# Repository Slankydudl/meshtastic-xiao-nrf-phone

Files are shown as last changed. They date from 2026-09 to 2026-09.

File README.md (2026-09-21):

<div align="center" markdown="1">

<h1>Meshtastic T9 Phone</h1>

PCB Render
Completed Device

</div>

## Overview
This repo contains all the needed PCB manufacturing files and 3D print files to turn your SEED XIAO nRF52840 & Wio-SX1262 Kit into the phone above... provided you're handy with a soldering iron.

</div>

### Additional Parts

- **[SEEED XIAO Kit](https://www.seeedstudio.com/XIAO-nRF52840-Wio-SX1262-Kit-for-Meshtastic-p-6400.html)**
- **[1.3" OLED](https://www.aliexpress.com/item/1005008934254841.html?spm=a2g0o.order_list.order_list_main.34.63fd1802lfZtmT)**
- **[2000mAh Battery](https://www.aliexpress.com/item/1005009571773727.html?spm=a2g0o.order_list.order_list_main.44.63fd1802lfZtmT)**

### Key Map

TBC

</div>

### Links
- **[Firmware](https://github.com/Slankydudl/firmware/tree/TCA8418_optimisations)** - Meshtastic firmware fork.
- **[Standalone Keypad](https://github.com/Slankydudl/T9-Keypad-Module)** - If you just want the keypad.
- **[onshape model](https://cad.onshape.com/documents/3c51ee3a5f6604343e4842f4/w/fb2a1c1f9218dcd275d16dea/e/b00e8f57d3ea05ff20d6055f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)** - If you want to copy and edit the 3D print in onshape.

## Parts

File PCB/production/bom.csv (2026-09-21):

Designator | Footprint | Quantity | Value | LCSC Part #
_6, _5 |  | 2
BUZZER1 | easyeda2kicad__BUZ-SMD_4P-L8.5-W8.5-P8.50-BR_d8af27ad9a | 1 | MLT-8530 | C94599
C1, C12 | PCM_JLCPCB__C_0402_5b7475e20d | 2 | 10uF | C15525
C10, C11, C2 | PCM_JLCPCB__C_0402_5b7475e20d | 3 | 100nF | C1525
C13 | PCM_JLCPCB__C_0402_5b7475e20d | 1 | 22pF | C1555
D2 | PCM_JLCPCB__D_SMA_5ba77312ee | 1 | SS14 | C2480
Q2 | PCM_JLCPCB__Q_SOT-23_0535f4caa0 | 1 | AO3400A | C20917
R1, R2 | PCM_JLCPCB__R_0805_38555c8e56 | 2 | 4.7kΩ | C17673
R12 | PCM_JLCPCB__R_0402_50b788cd01 | 1 | 100Ω | C25076
R13 | PCM_JLCPCB__R_0402_50b788cd01 | 1 | 100kΩ | C25741
R14, R15 | PCM_JLCPCB__R_0805_38555c8e56 | 2 | 0Ω | C17477
R3, R4 | PCM_JLCPCB__R_0402_50b788cd01 | 2 | 10kΩ | C25744
SW1, SW10, SW11, SW12, SW2, SW3, SW4, SW5, SW6, SW7, SW8, SW9 | easyeda2kicad__TS-1187A-B-A-B_2a0d7a9c99 | 12 | TS-1187A-B-A-B | C318884
U1 | easyeda2kicad__TCA8418RTWR_3b4f66023a | 1 | TCA8418RTWR | C138713

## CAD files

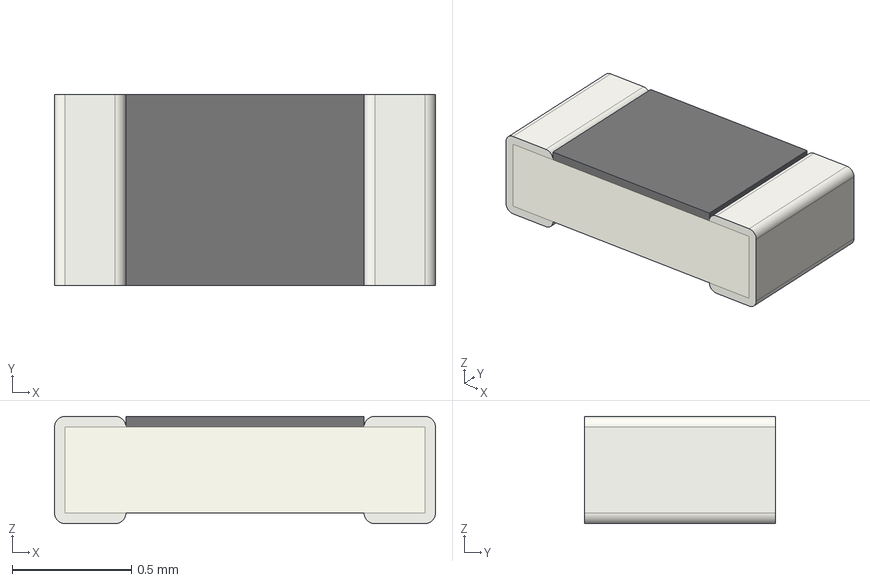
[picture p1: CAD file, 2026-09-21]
PCB/3D Models/R_0603_da4c2ea7ab.step
1.60 x 0.8 x 0.45 mm

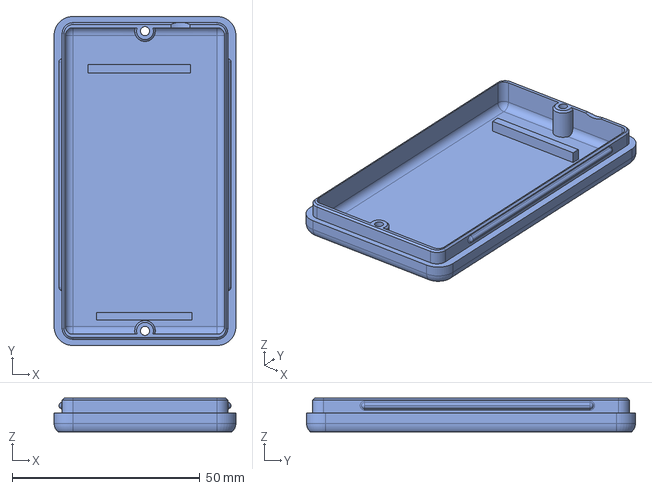
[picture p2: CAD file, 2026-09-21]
Print/Bottom Shell.step
48.4 x 87.6 x 8.95 mm

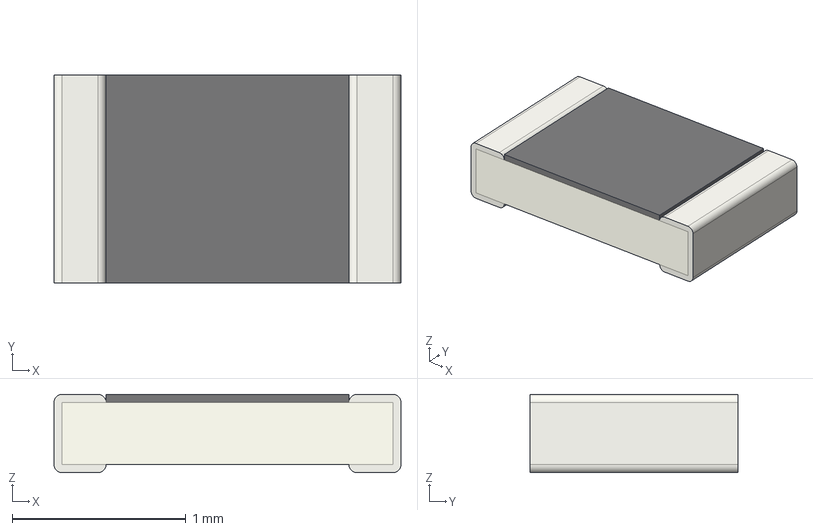
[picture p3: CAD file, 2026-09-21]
PCB/3D Models/R_0805_02b1576828.step
2.00 x 1.20 x 0.45 mm

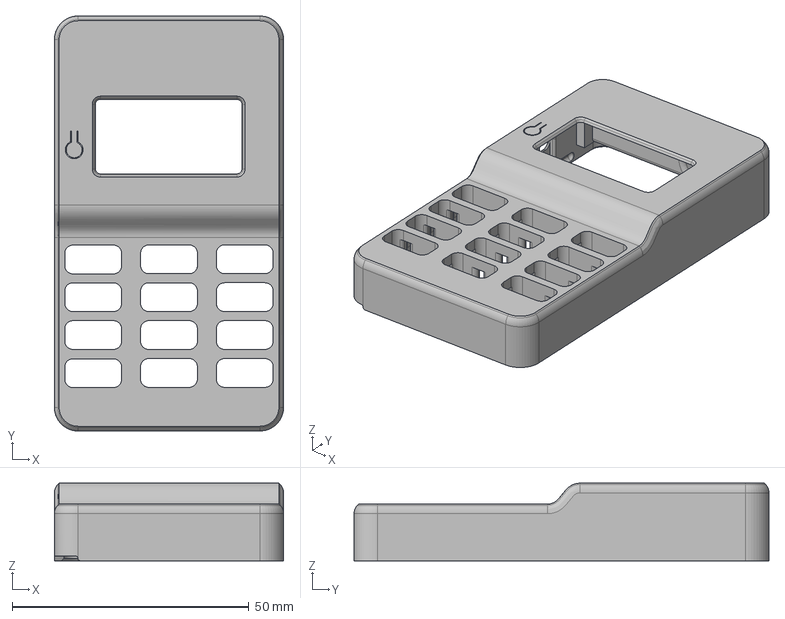
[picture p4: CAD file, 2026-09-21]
Print/Top Shell.step
48.4 x 87.6 x 16.4 mm

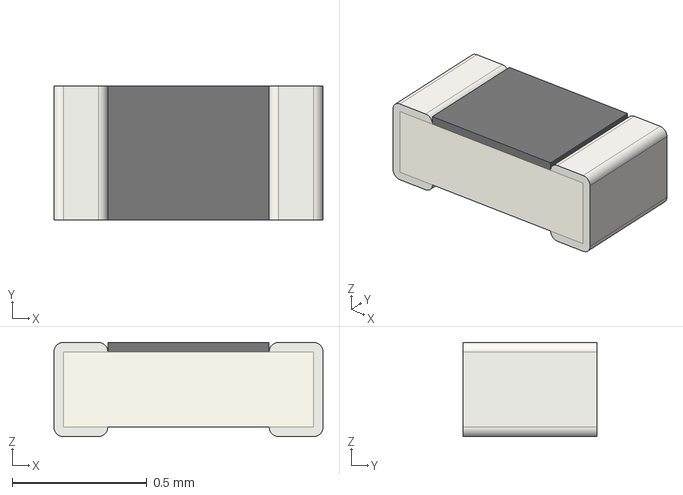
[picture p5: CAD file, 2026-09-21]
PCB/3D Models/R_0402_9dcb716b28.step
1.00 x 0.5 x 0.35 mm

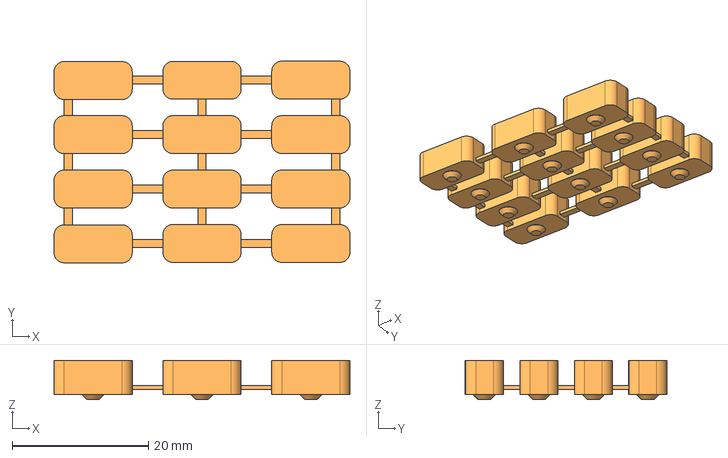
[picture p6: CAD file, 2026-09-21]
Print/Keypad.step
43.5 x 29.6 x 5.80 mm

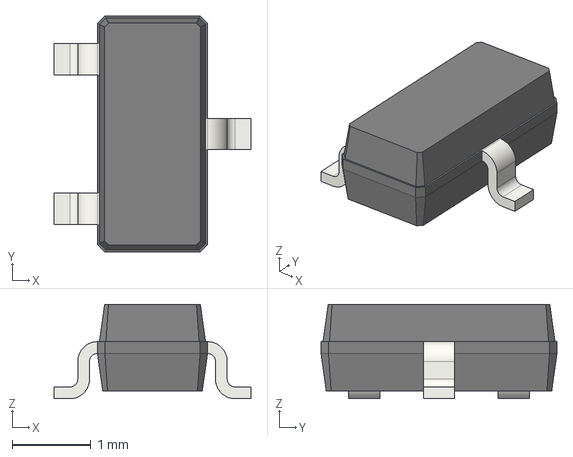
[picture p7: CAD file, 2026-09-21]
PCB/3D Models/Q_SOT-23_90a21f5ec4.step
2.50 x 3.00 x 1.20 mm

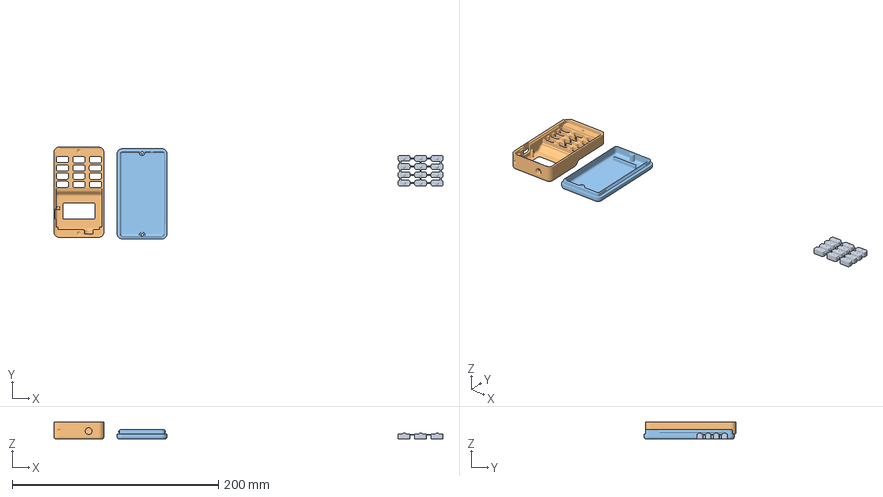
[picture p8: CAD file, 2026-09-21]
Print/Print.3mf
377.3 x 89.2 x 16.4 mm
Keypad.step
Top Shell.step
Bottom Shell.step

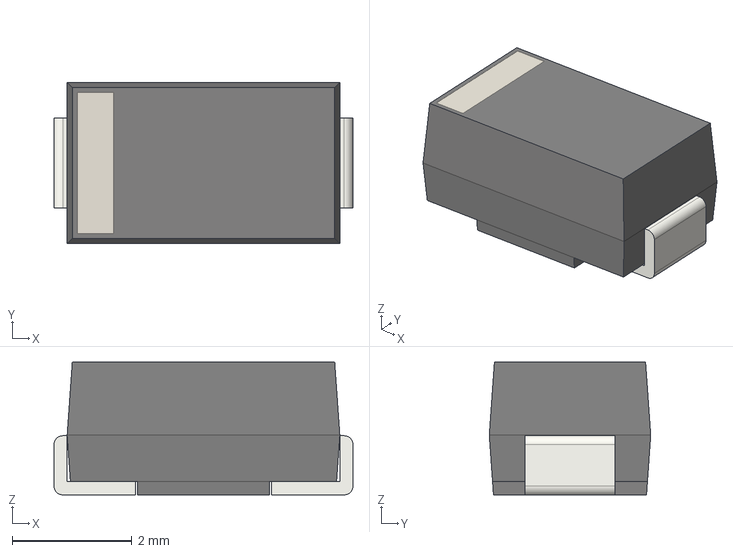
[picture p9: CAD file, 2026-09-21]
PCB/3D Models/D_SMA_7a0e4ea444.step
5.00 x 2.70 x 2.22 mm

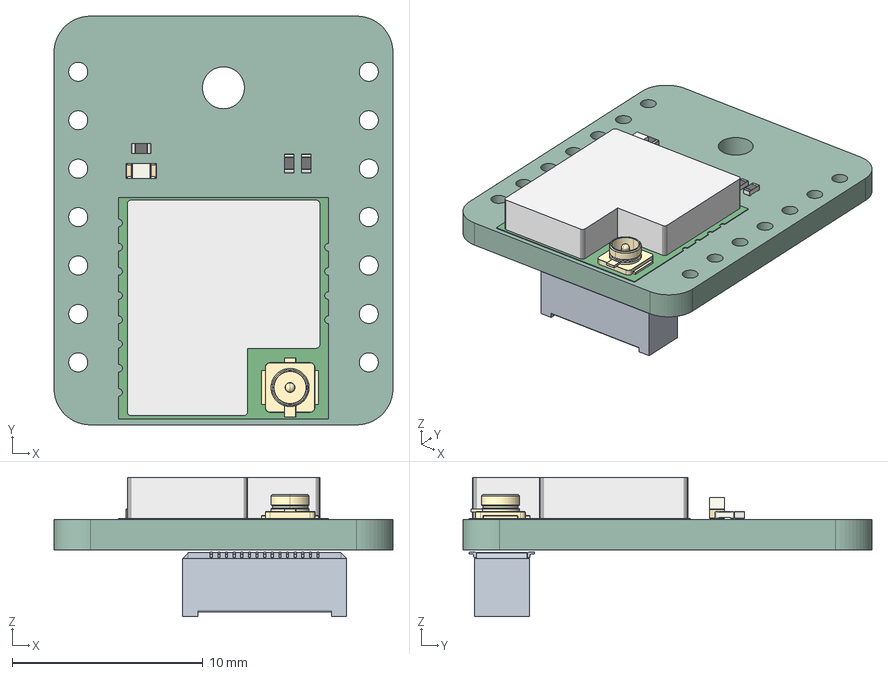
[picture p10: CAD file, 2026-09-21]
PCB/3D Models/wio-sx1262_for_xiao_3d_file (1)_c7fd3d64ef.step
17.8 x 21.4 x 7.30 mm
R_0402_1005Metric x 3
LED_0603_1608Metric
PCB
BF04-30pin-35H
Wio-SX1262 for XIAO V1.0_PCB

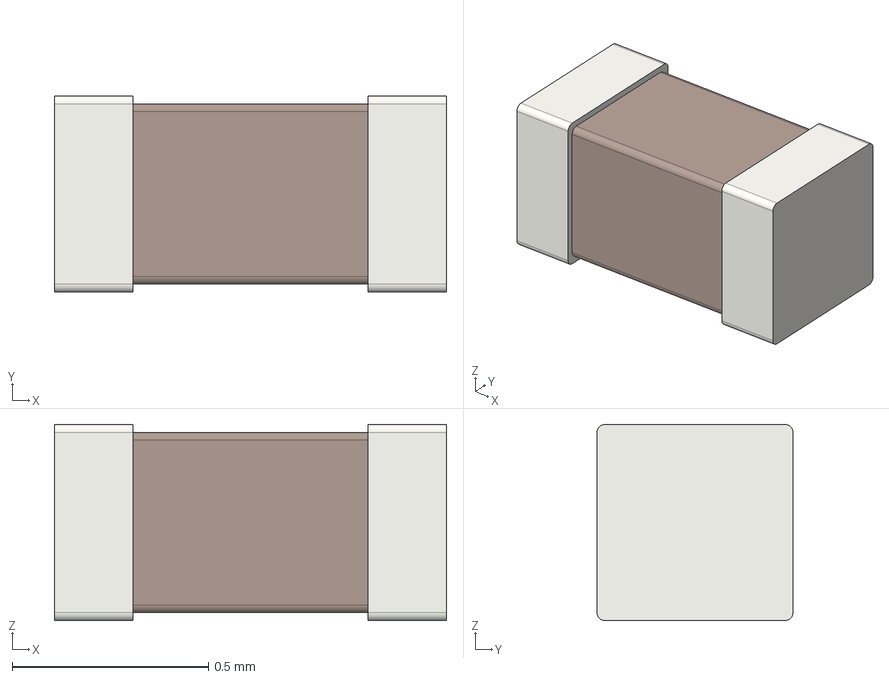
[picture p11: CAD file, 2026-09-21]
PCB/3D Models/C_0402_0a528c0bbe.step
1.00 x 0.5 x 0.5 mm

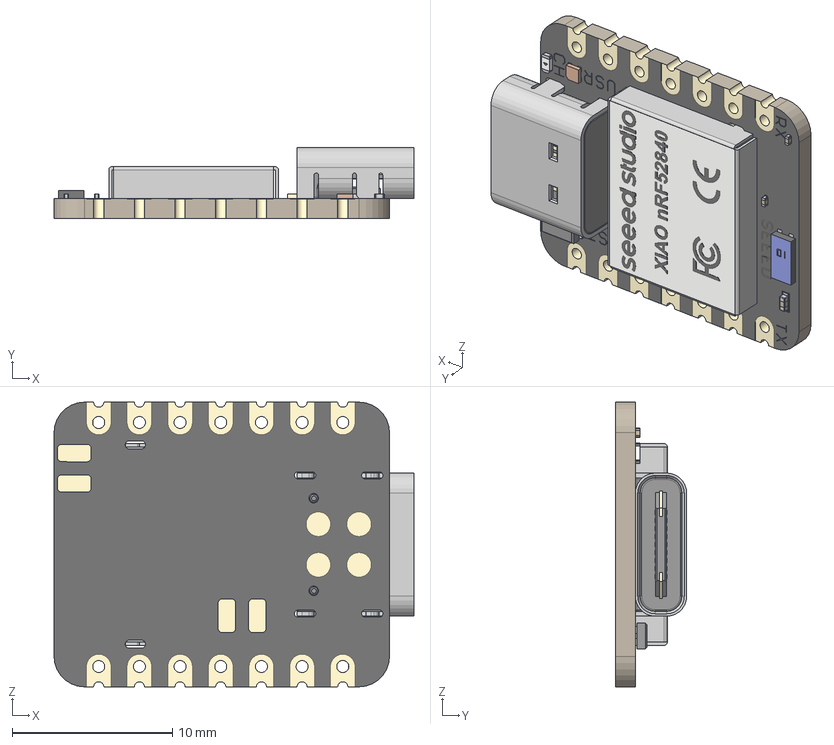
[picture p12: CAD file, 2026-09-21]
PCB/3D Models/xiao-nrf52840-v3_e11c217d7b.step
22.5 x 4.46 x 17.8 mm
BOSS-EXTRUDE14_8_
BOSS-EXTRUDE7_4_
BOSS-EXTRUDE7_3_
BOSS-EXTRUDE14_4_
BOSS-EXTRUDE14_2_
BOSS-EXTRUDE14_11_
BOSS-EXTRUDE7_7_
BOSS-EXTRUDE14_9_
BOSS-EXTRUDE14_3_
BOSS-EXTRUDE14_7_
MIRROR2
BOSS-EXTRUDE14_5_
BOSS-EXTRUDE14_12_
BOSS-EXTRUDE7_8_
BOSS-EXTRUDE7_1_
BOSS-EXTRUDE14_10_
BOSS-EXTRUDE7_9_
BOSS-EXTRUDE14_6_
BOSS-EXTRUDE14_1_
BOSS-EXTRUDE7_6_
BOSS-EXTRUDE7_2_
CUT-EXTRUDE5
BOSS-EXTRUDE7_5_
Shield
Pins
CAP x 2
ANT1
Silkscreen
CAP 3
LED
USR
MSM261D3526H1CPM

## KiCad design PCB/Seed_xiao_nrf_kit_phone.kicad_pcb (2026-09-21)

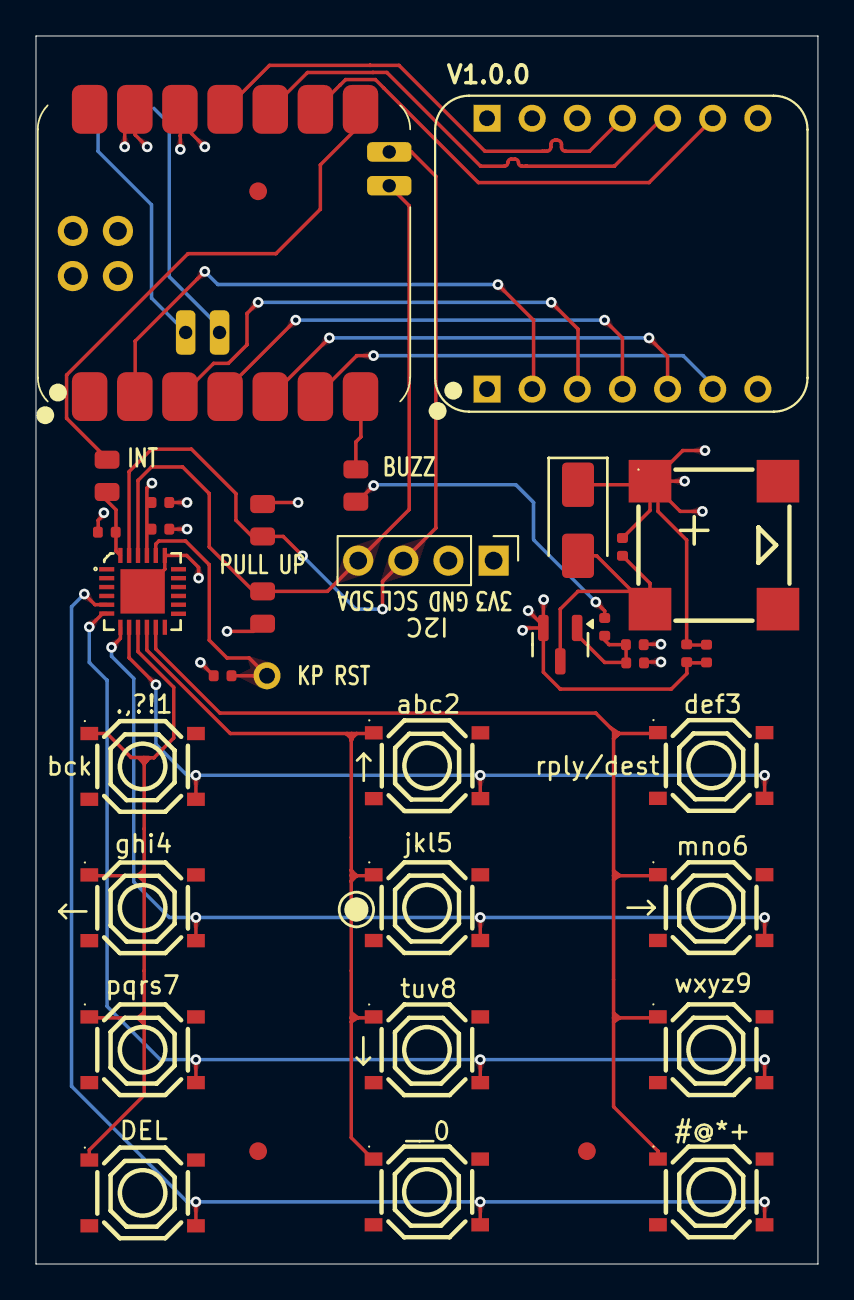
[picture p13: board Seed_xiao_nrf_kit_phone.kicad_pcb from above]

Board: 4 copper layers, 44.0 x 69.1 mm, 33 parts (0 on the bottom side), 26 nets.

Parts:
BUZZER1: MLT-8530; easyeda2kicad__BUZ-SMD_4P-L8.5-W8.5-P8.50-BR_d8af27ad9a
C1, C12: 10uF; PCM_JLCPCB__C_0402_5b7475e20d
C2, C10, C11: 100nF; PCM_JLCPCB__C_0402_5b7475e20d
C13: 22pF; PCM_JLCPCB__C_0402_5b7475e20d
D2: SS14; PCM_JLCPCB__D_SMA_5ba77312ee
J1: 4pin header; Self_Made__4Pin header_d1808ed7c5
Q2: AO3400A; PCM_JLCPCB__Q_SOT-23_0535f4caa0
R1, R2: 4.7kΩ; PCM_JLCPCB__R_0805_38555c8e56
R3, R4: 10kΩ; PCM_JLCPCB__R_0402_50b788cd01
R12: 100Ω; PCM_JLCPCB__R_0402_50b788cd01
R13: 100kΩ; PCM_JLCPCB__R_0402_50b788cd01
R14, R15: 0Ω; PCM_JLCPCB__R_0805_38555c8e56
SW1, SW2, SW3, SW4, SW5, SW6, SW7, SW8, SW9, SW10, SW11, SW12: TS-1187A-B-A-B; easyeda2kicad__TS-1187A-B-A-B_2a0d7a9c99
U1: TCA8418RTWR; easyeda2kicad__TCA8418RTWR_3b4f66023a
U2: XIAO-nRF52840-SMD; XIAO_Series_Footprints__XIAO-nRF52840-SMD_Vias_a8f4777abb
U9: WIO-SX1262-DIP; Self_Made__WIO-SX1262-DIP_83e7a100c9

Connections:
+3V3: BUZZER1.1 (+), C1.1, C2.1, C10.1, C11.1, C12.1, D2.1, J1.1, R1.1, R2.1, R3.1, R4.1, U1.21 (VCC), U2.12 (3V3), U9.12 (3V3)
/Buzz: R12.2, R14.1
/Column_0: SW1.1 (A), SW2.1 (A), SW3.1 (A), SW4.1 (A), U1.9 (COL0)
/Column_1: SW5.1 (A), SW6.1 (A), SW7.1 (A), SW8.1 (A), U1.10 (COL1)
/Column_2: SW9.1 (A), SW10.1 (A), SW11.1 (A), SW12.1 (A), U1.11 (COL2)
/INT: R3.2, R15.1, U1.24 (~INT)
/RST: R4.2, U1.20 (~RESET)
/Row_0: SW1.4 (D), SW5.4 (D), SW9.4 (D), U1.8 (ROW0)
/Row_1: SW2.4 (D), SW6.4 (D), SW10.4 (D), U1.7 (ROW1)
/Row_2: SW3.4 (D), SW7.4 (D), SW11.4 (D), U1.6 (ROW2)
/Row_3: SW4.4 (D), SW8.4 (D), SW12.4 (D), U1.5 (ROW3)
/SCL: J1.3, R1.2, U1.23 (SCL), U2.35 (P0.10_NFC2)
/SDA: J1.4, R2.2, U1.22 (SDA), U2.34 (P0.09_NFC1)
GND: C1.2, C2.2, C11.2, C12.2, C13.2, J1.2, Q2.2 (S), R13.2, U1.19 (GND), U1.25 (EP), U2.13 (GND), U9.13 (GND)
unnamed: BUZZER1.2, C10.2, D2.2, Q2.3 (D)
unnamed: C13.1, Q2.1 (G), R12.1, R13.1
unnamed: U2.2 (P0.03_A1_D1), U9.2 (DIO1)
unnamed: U2.5 (P0.04_A4_D4_SDA), U9.5 (NSS)
unnamed: U2.6 (P0.05_A5_D5_SCL), U9.6 (RF_SW)
unnamed: U2.3 (P0.28_A2_D2), U9.3 (RST)
unnamed: U2.4 (P0.29_A3_D3), U9.4 (BUSY)
unnamed: R14.2, U2.7 (P1.11_D6_TX)
unnamed: R15.2, U2.8 (P1.12_D7_RX)
unnamed: U2.9 (P1.13_D8_SCK), U9.9 (SCK)
unnamed: U2.10 (P1.14_D9_MISO), U9.10 (MISO)
unnamed: U2.11 (P1.15_D10_MOSI), U9.11 (MOSI)

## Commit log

2026-09-21 fixed XIAO showing on BOM & POS
    [Seed_xiao_nrf_kit_phone.kicad_pcb, Seed_xiao_nrf_kit_phone.kicad_sch, bom.csv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]
2026-09-21 Added print files
    [Bottom Shell.step, Keypad.step, Print.3mf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]
2026-09-21 Add Onshape model link to README
    Added link to Onshape model for 3D print.
2026-09-21 Add images to README
    Added images of PCB render and completed device to README.

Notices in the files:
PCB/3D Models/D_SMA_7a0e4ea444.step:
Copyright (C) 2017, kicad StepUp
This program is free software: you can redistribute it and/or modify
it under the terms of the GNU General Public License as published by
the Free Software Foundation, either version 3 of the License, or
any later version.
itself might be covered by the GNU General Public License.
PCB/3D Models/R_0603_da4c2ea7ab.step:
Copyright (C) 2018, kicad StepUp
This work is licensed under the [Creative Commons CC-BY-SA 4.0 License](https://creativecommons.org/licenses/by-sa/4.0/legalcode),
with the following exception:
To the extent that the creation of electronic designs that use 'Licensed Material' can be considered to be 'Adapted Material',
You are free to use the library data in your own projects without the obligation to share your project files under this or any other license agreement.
